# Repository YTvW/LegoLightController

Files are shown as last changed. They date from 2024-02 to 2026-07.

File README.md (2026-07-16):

# QBee LED Controller

A LEGO-stud-compatible LED controller board (Rev 1.0) built around the ATSAMD11C14A,
powered over USB-C. It drives up to two WS2812B (NeoPixel) strips and three
single-color LED channels.

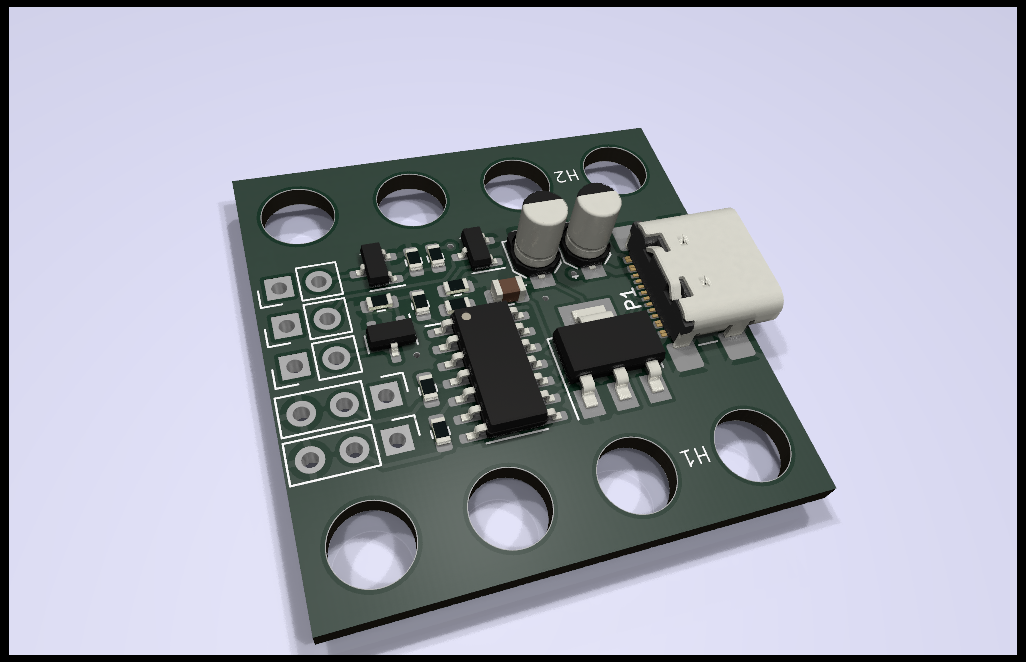
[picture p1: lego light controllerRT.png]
Board render


## Hardware overview

| Part | Function |
|---|---|
| U1 — ATSAMD11C14A (SOIC-14) | MCU, 16KB flash / 4KB RAM, native USB |
| U2 — AP2111H-3.3 | 3.3V LDO for the MCU |
| P1 — USB-C (USB4110) | Power (5V) + USB 2.0 data; 5.1k CC pulldowns identify the board as a power sink |
| Q1–Q3 — BC847 | Low-side switches for the three LED channels (1k base, 10k pulldown) |
| R10, R11 — 470Ω | Series resistors on the WS2812B data lines |

### Connectors / IO

| Connector | Pads | Signal | MCU pin | Arduino pin |
|---|---|---|---|---|
| J1 | 1: +5V, 2: switched GND | LED1 channel | PA02 | 2 |
| J2 | 1: +5V, 2: switched GND | LED2 channel | PA04 | 4 |
| J3 | 1: +5V, 2: switched GND | LED3 channel | PA05 | 5 |
| J4 | 1: +5V, 2: data, 3: GND | WS2812B strip (DL1) | PA14 | 14 |
| J5 | 1: +5V, 2: data, 3: GND | WS2812B strip (DL2) | PA15 | 15 |
| J7 | 1: 3V3, 2: RESET, 3: SWCLK, 4: SWDIO, 5: NC, 6: GND | SWD programming header (DNP) | PA28/PA30/PA31 | — |
| TP1 | test point | EXT1 spare GPIO | PA08 | 8 |
| TP2 | test point | EXT2 spare GPIO | PA09 | 9 |

The LED channels (J1–J3) switch the LED's ground side through a transistor:
connect an LED (with its own series resistor if needed) between pad 1 (+5V)
and pad 2. A HIGH on the MCU pin turns the channel on.

Notes per pin:

- **PA02 (LED1, pin 2)** has no timer output — hardware PWM is not possible.
  `analogWrite()` on this pin uses the true 10-bit DAC; the transistor makes
  this behave as a crude analog dimmer only. Prefer channels LED2/LED3 for
  smooth PWM dimming.
- **PA04/PA05 (LED2/LED3)** have TC1 waveform outputs (WO0/WO1) — used by
  `pwm_driver` channels 0 and 1.
- **PA14/PA15 (strips)** also carry TC1 outputs; do not `analogWrite()` them.

## Arduino environment setup

1. Install the [Arduino IDE](https://www.arduino.cc/en/software) (2.x).
2. Add the Fab SAM core: **File → Preferences → Additional boards manager URLs**:

   ```
   https://raw.githubusercontent.com/qbolsee/ArduinoCore-fab-sam/master/json/package_Fab_SAM_index.json
   ```

3. **Tools → Board → Boards Manager**, search "Fab SAM", install
   **Fab SAM core for Arduino** (this project was built with 1.12.0).
4. Select **Tools → Board → Fab SAM boards → Generic D11C14A**.

### Board settings (Tools menu)

| Setting | Value | Notes |
|---|---|---|
| Clock Source | `INTERNAL_USB_CALIBRATED_OSCILLATOR` | Crystalless; calibrates 48MHz from USB. Switch to `INTERNAL_OSCILLATOR` if USB is disabled. |
| Bootloader Size | `4KB_BOOTLOADER` | Leaves 12KB for the application |
| Serial Config | `NO_UART_ONE_WIRE_ONE_SPI` | Saves ~1.5KB vs the default; USB `Serial` still works. The hardware UART (`Serial1`) is not wired to anything on this board. |
| USB Config | `CDC_ONLY` | Needed for `Serial` debugging and one-click uploads |
| Float | default | |
| Timer PWM Frequency | default (732.4Hz) | Only affects `analogWrite()` |

### Uploading

Normal uploads go over USB via the SAM-BA bootloader: just press Upload —
the IDE opens the port at 1200 baud to reset the board into the bootloader
automatically (this requires the running sketch to have USB CDC enabled).

If the chip is blank, or the sketch was built without CDC, flash via the SWD
pads (J7) with a CMSIS-DAP programmer and
[edbg](https://github.com/ataradov/edbg), or use the IDE's
*Burn Bootloader* with the Fab programmer selected. Once the bootloader is
on, USB uploads work as above.

## Firmware (`QBee Software/QBeeFirmware`)

| File | Purpose |
|---|---|
| `QBeeFirmware.ino` | Main sketch |
| `ws2812b_dma_driver.c/h` | WS2812B driver using **TCC0** PWM + DMA. Non-blocking: `ws2812b_show()` starts a hardware transfer and returns immediately. Uses TCC0's double-buffered `CCB` compare register so bit timing is glitch-free and immune to interrupts/USB load. |
| `pwm_driver.c/h` | LED-channel PWM using **TC1** (channels 0/1 → pins 4/5). TC2 exists but its outputs land on the SWD pins only. Costs no flash while unused (linker GC). |
| `neopixel_driver.c/h` | Older bit-banged WS2812B driver (blocks with interrupts off; superseded by the DMA driver) |

### Timer budget

| Peripheral | Owner |
|---|---|
| TCC0 | `ws2812b_dma_driver` (do not combine with `analogWrite`/`pwm_driver` on TCC0 pins) |
| TC1 | `pwm_driver` channels 0/1 (pins 4/5). Also claimed by `tone()` — don't use both. |
| TC2 | `pwm_driver` channels 2/3 — outputs only on SWD pins PA30/PA31, effectively unusable |
| SysTick | `millis()`/`micros()`/`delay()` (not a shared peripheral) |
| DMAC ch 0 | `ws2812b_dma_driver` |

### Flash budget

The app space is 12288 bytes. Measured levers if space runs out:

| Change | Approx. saving |
|---|---|
| Serial Config → `NO_UART...` | 1.5KB (free — `Serial1` unused) |
| USB Config → `WITHOUT_CDC` (drop `Serial` prints) | +2KB |
| USB Config → `USB_DISABLED` (also set Clock → `INTERNAL_OSCILLATOR`) | +4KB more |
| Bootloader → `NO_BOOTLOADER` (SWD uploads only) | +4KB of app space |

## Known hardware issues (Rev 1.0)

- **No level shifter on the WS2812B data lines.** Data is 3.3V while the
  strip runs at 5V; the strip's VIH spec is 0.7×VDD = 3.5V, so operation
  relies on real-world margin. Symptom: strips work on a USB-C wall supply
  but fail or glitch on some PC ports (slightly higher/noisier VBUS).
  Workaround: a silicon diode in series with the strip's +5V feed (drops
  strip VDD to ~4.4V). Proper fix for Rev 2: a 74AHCT1G125 / SN74LV1T125
  buffer on each data line, powered from 5V.
- **LED1 (PA02) has no hardware PWM** — see pin notes above.

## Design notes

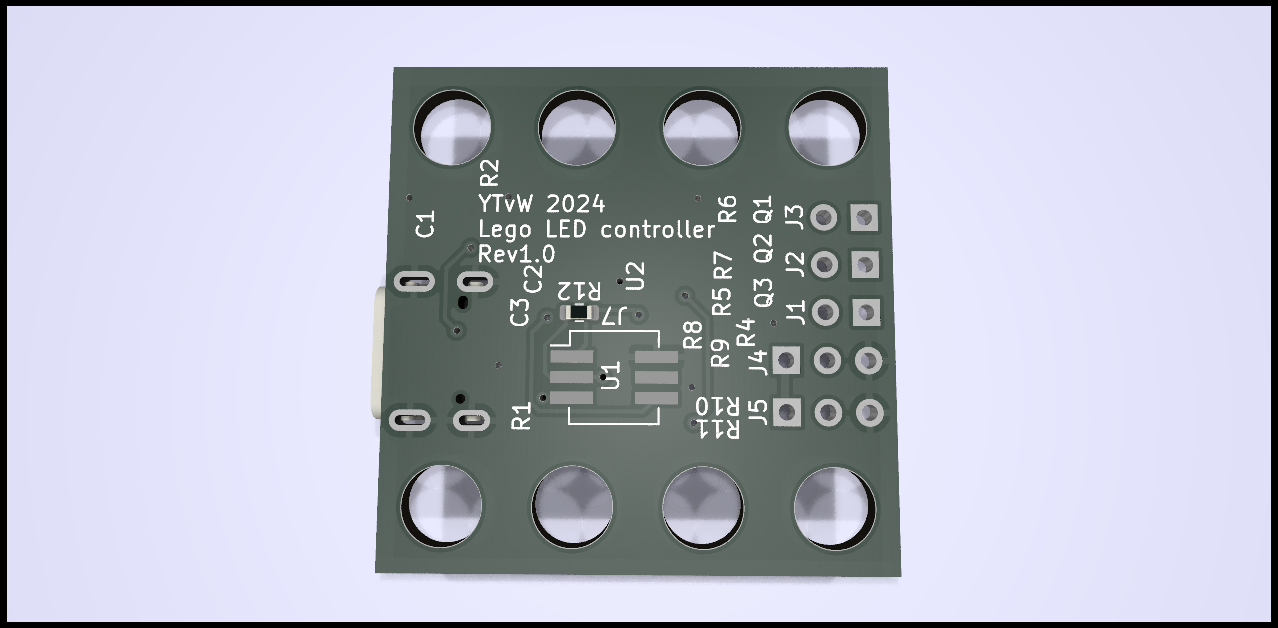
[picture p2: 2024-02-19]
lego light controllerRT2.png

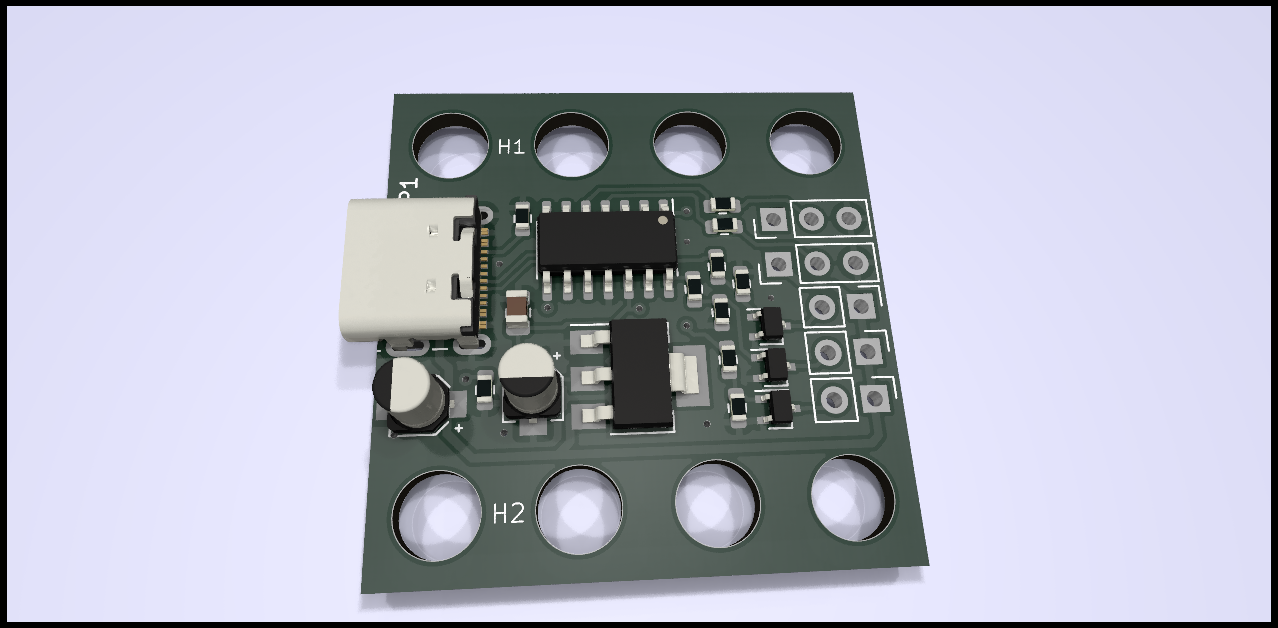
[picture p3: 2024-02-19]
lego light controllerRT1.png

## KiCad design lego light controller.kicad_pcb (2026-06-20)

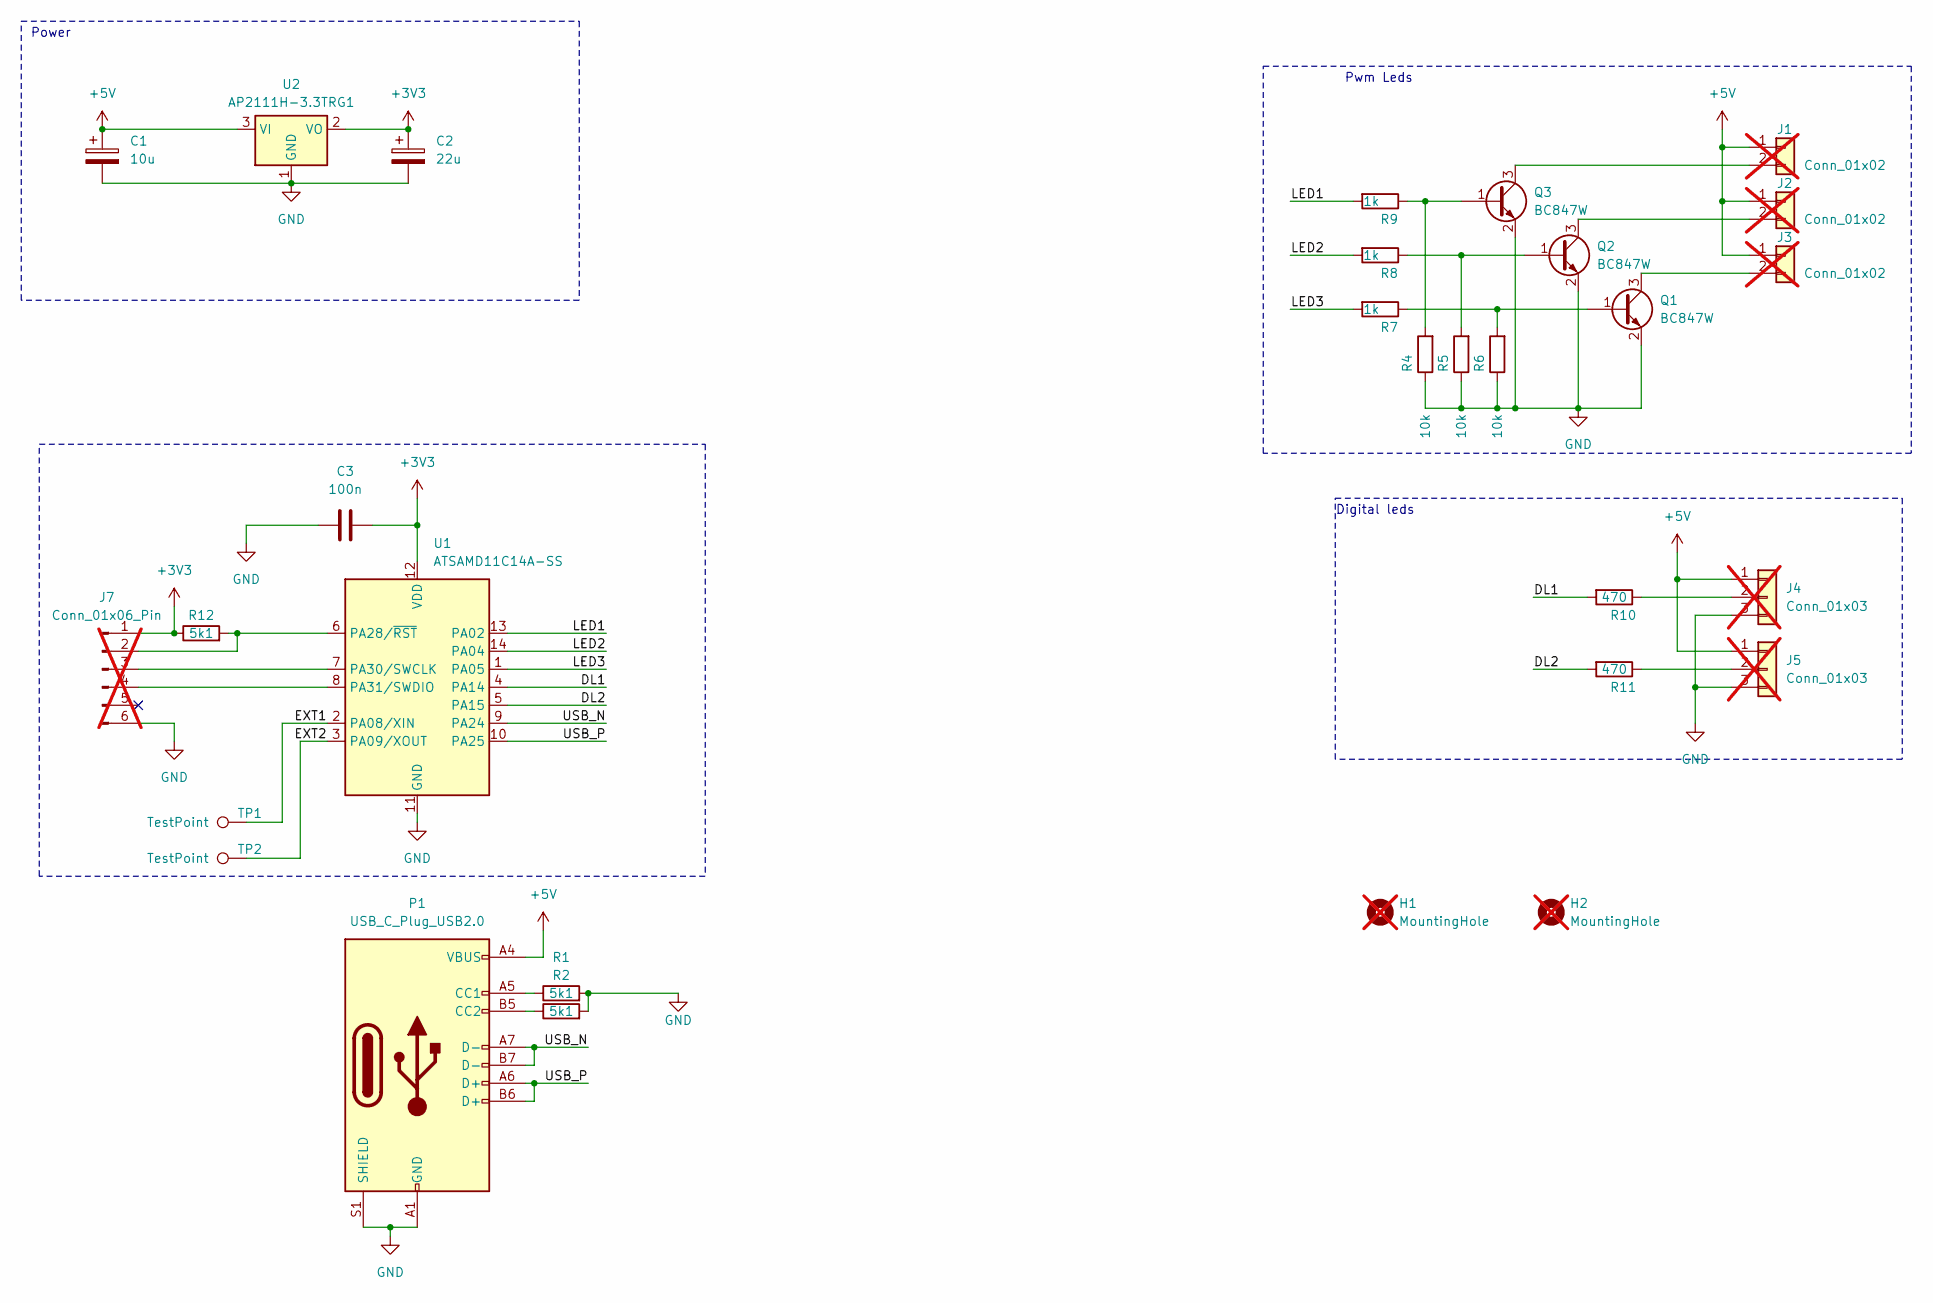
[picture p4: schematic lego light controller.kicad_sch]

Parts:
C1: 10u; CP_Elec_3x5.3; MPN 875105240001
C2: 22u; CP_Elec_3x5.3; MPN 875105240003
C3: 100n; C_0805_2012Metric
H1, H2: MountingHole; LEGO 4Studs; not fitted
J1, J2, J3: Conn_01x02; PinHeader_1x02_P2.54mm_Vertical; not fitted
J4, J5: Conn_01x03; PinHeader_1x03_P2.54mm_Vertical; not fitted
J7: Conn_01x06_Pin; SW_DIP_SPSTx03_Slide_KingTek_DSHP03TJ_W5.25mm_P1.27mm_JPin; not fitted
P1: USB_C_Plug_USB2.0; USB_C_Receptacle_GCT_USB4110; MPN USB4110-GF-A
Q1, Q2, Q3: BC847W; SOT-23; MPN BC817-16LT3G
R1, R2, R12: 5k1; R_0603_1608Metric
R4, R5, R6: 10k; R_0603_1608Metric
R7, R8, R9: 1k; R_0603_1608Metric
R10, R11: 470; R_0603_1608Metric
TP1, TP2: TestPoint; TestPoint_Pad_2.0x2.0mm
U1: ATSAMD11C14A-SS; SOIC-14_3.9x8.7mm_P1.27mm; MPN ATSAMD11C14A-SSNT
U2: AP2111H-3.3TRG1; SOT-223-3_TabPin2; MPN AP2111H-3.3TRG1

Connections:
+3V3: C2.1, C3.2, J7.1, R12.1, U1.12 (VDD), U2.2 (VO)
+5V: C1.1, J1.1, J2.1, J3.1, J4.1, J5.1, P1.A4 (VBUS), P1.A9 (VBUS), P1.B4 (VBUS), P1.B9 (VBUS), U2.3 (VI)
/DL1: R10.2, U1.4 (PA14)
/DL2: R11.2, U1.5 (PA15)
/EXT1: TP1.1 (1_1), U1.2 (PA08/XIN)
/EXT2: TP2.1 (1_1), U1.3 (PA09/XOUT)
/LED1: R9.2, U1.13 (PA02)
/LED2: R8.2, U1.14 (PA04)
/LED3: R7.2, U1.1 (PA05)
/USB_N: P1.A7 (D-), P1.B7 (D-), U1.9 (PA24)
/USB_P: P1.A6 (D+), P1.B6 (D+), U1.10 (PA25)
GND: C1.2, C2.2, C3.1, J4.3, J5.3, J7.6, P1.A1 (GND), P1.A12 (GND), P1.B1 (GND), P1.B12 (GND), P1.S1 (SHIELD), Q1.2 (E), Q2.2 (E), Q3.2 (E), R1.2, R2.2, R4.1, R5.1, R6.1, U1.11 (GND), U2.1 (GND)
unnamed: J1.2, Q3.3 (C)
unnamed: J2.2, Q2.3 (C)
unnamed: J3.2, Q1.3 (C)
unnamed: J4.2, R10.1
unnamed: J5.2, R11.1
unnamed: J7.2, R12.2, U1.6 (PA28/~RST)
unnamed: J7.3, U1.7 (PA30/SWCLK)
unnamed: J7.4, U1.8 (PA31/SWDIO)
unnamed: P1.A5 (CC1), R1.1
unnamed: P1.B5 (CC2), R2.1
unnamed: Q1.1 (B), R6.2, R7.1
unnamed: Q2.1 (B), R5.2, R8.1
unnamed: Q3.1 (B), R4.2, R9.1

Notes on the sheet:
Power
Pwm Leds
Digital leds

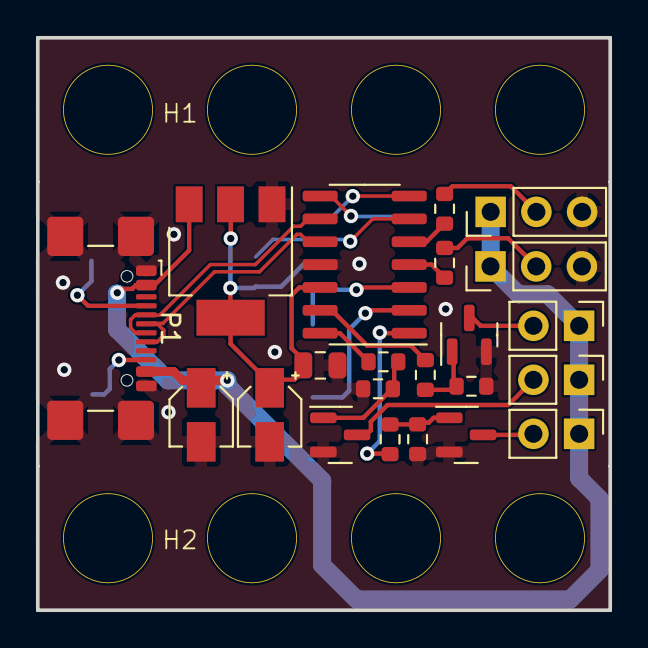
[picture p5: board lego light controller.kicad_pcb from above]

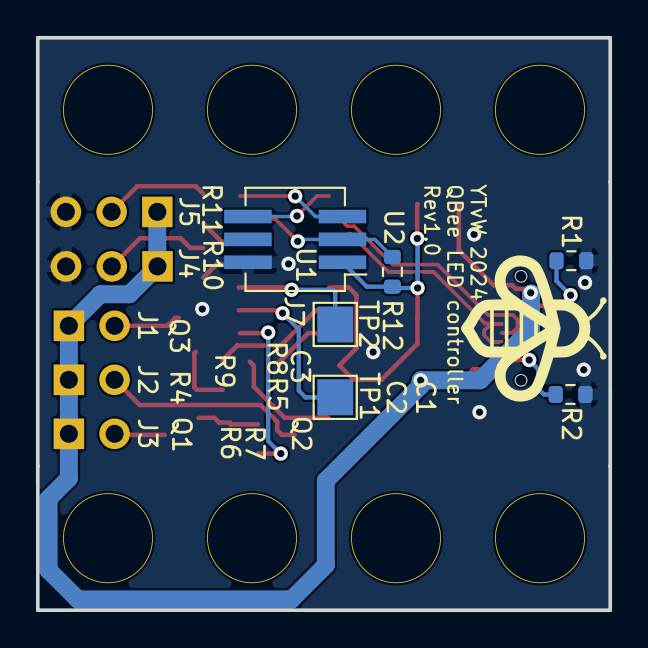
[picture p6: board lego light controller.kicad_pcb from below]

Board: 2 copper layers, 31.8 x 31.8 mm, 30 parts (6 on the bottom side), 25 nets.

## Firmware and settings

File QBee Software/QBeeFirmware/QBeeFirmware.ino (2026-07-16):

// #include <Adafruit_NeoPixel.h>
// #include "pwm_driver.h"
// #include "neopixel_driver.h"
#include "ws2812b_dma_driver.h"

ws2812b_strip_t strip;
ws2812b_strip_t strip2;

#define PIXEL_PIN_1 15
#define PIXEL_PIN_2 14

#define PWM_PIN_2 4
#define PWM_PIN_3 5

// constants won't change. Used here to set a pin number:
const int ledPin1 = 2;
const int ledPin2 = PWM_PIN_2;
const int ledPin3 = PWM_PIN_3;

int ledState = 0;  // ledState used to set the LED

unsigned long previousMillis = 0;  // will store last time LED was updated

const long interval = 500;  // interval at which to blink (milliseconds)

// neopixel_strip_t strip;
// neopixel_strip_t strip2;

// Adafruit_NeoPixel strip1 = Adafruit_NeoPixel(8, PIXEL_PIN_1, NEO_GRB + NEO_KHZ800);

void setup() {
  Serial.begin(115200);
  // while (!Serial) {
  //   ;  // wait for serial port to connect. Needed for native USB port only
  // }    // prints title with ending line break
  Serial.println("running set up");
  pinMode(ledPin1, OUTPUT);
  pinMode(ledPin2, OUTPUT);
  pinMode(ledPin3, OUTPUT);

  ws2812b_init(&strip, PIXEL_PIN_1, 8, WS2812B_GRB, NULL);
  ws2812b_init(&strip2, PIXEL_PIN_2, 8, WS2812B_GRB, NULL);
  ws2812b_set_brightness(&strip, 64);

  ws2812b_fill(&strip, 0, 0, 0);
  ws2812b_fill(&strip2, 0, 0, 0);
  ws2812b_show(&strip);
  ws2812b_show(&strip2);
}
uint8_t ledNr = 0;
uint32_t colour =ws2812b_color(255, 255,255);
void loop() {

  // check to see if it's time to blink the LED; that is, if the difference
  // between the current time and last time you blinked the LED is bigger than
  // the interval at which you want to blink the LED.
  unsigned long currentMillis = millis();

  if (currentMillis - previousMillis >= interval) {
    // save the last time you blinked the LED

    previousMillis = currentMillis;
    Serial.print("ledNr: ");
    Serial.println(ledNr);
    // if the LED is off turn it on and vice-versa:
    ws2812b_set_pixel_color(&strip, ledNr, colour);
    if (ledState == 64) {
      ledState = 200;

    } else {
      


      ledState = 64;
    }

    // CPU is free while LEDs update
    if (ws2812b_is_ready(&strip)) {
      // Start next update
      Serial.println("updating leds: ");

      ws2812b_show(&strip);
    } else {
      Serial.println("leds not ready");
    }
    ledNr += 1;
    if (ledNr >= 8) {
      ledNr = 0;
      Serial.print("colour");
      Serial.println(colour);
      if (colour == 0) {
      colour = ws2812b_color(255, 0,0);
      }else {
      colour = ws2812b_color(0, 0,0);
      
      }
    }
    // neopixel_show(&strip);
    // strip1.show();
    // pwm_set_duty(PWM_CHANNEL_2, ledState);  // 50%
    // pwm_set_duty(PWM_CHANNEL_3, 64);   // 25%
    //   // set the LED with the ledState of the variable:
    // analogWrite(ledPin2, ledState);
    // analogWrite(ledPin3, 255 - ledState);
  }

  //  rainbowCycle(strip2,20);
}

// Slightly different, this makes the rainbow equally distributed throughout
// void rainbowCycle(Adafruit_NeoPixel strip, uint8_t wait) {
//   uint16_t i, j;

//   for (j = 0; j < 256 * 5; j++) {  // 5 cycles of all colors on wheel
//     for (i = 0; i < strip.numPixels(); i++) {
//       strip.setPixelColor(i, Wheel(strip, ((i * 256 / strip.numPixels()) + j) & 255));
//     }
//     strip.show();
//     delay(wait);
//   }
// }

// Input a value 0 to 255 to get a color value.
// The colours are a transition r - g - b - back to r.
// uint32_t Wheel(Adafruit_NeoPixel strip, byte WheelPos) {
//   WheelPos = 255 - WheelPos;
//   if (WheelPos < 85) {
//     return strip.Color(255 - WheelPos * 3, 0, WheelPos * 3);
//   }
//   if (WheelPos < 170) {
//     WheelPos -= 85;
//     return strip.Color(0, WheelPos * 3, 255 - WheelPos * 3);
//   }
//   WheelPos -= 170;
//   return strip.Color(WheelPos * 3, 255 - WheelPos * 3, 0);
// }

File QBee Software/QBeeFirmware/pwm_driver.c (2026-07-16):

/**
 * @file pwm_driver.c
 * @brief TC-based PWM driver implementation for SAMD11C / SAMD21
 *
 * Uses two TC instances in 8-bit PWM mode, leaving TCC0 free for the
 * WS2812B DMA driver:
 *   - SAMD11C: TC1 (channels 0-1) and TC2 (channels 2-3)
 *   - SAMD21:  TC3 (channels 0-1) and TC4 (channels 2-3)
 */

#include "pwm_driver.h"

// The two TC instances backing the four PWM channels, and their GCLK
// channel IDs. On the SAMD11 TC1/TC2 share one GCLK channel; on the
// SAMD21 TC3 (paired with TCC2) and TC4 (paired with TC5) each sit on
// their own.
#if defined(_SAMD21_)
#define PWM_TC_A TC3
#define PWM_TC_B TC4
#define PWM_TC_A_GCLK_ID TC3_GCLK_ID
#define PWM_TC_B_GCLK_ID TC4_GCLK_ID
#define PWM_APBCMASK (PM_APBCMASK_TC3 | PM_APBCMASK_TC4)
#else // _SAMD11_
#define PWM_TC_A TC1
#define PWM_TC_B TC2
#define PWM_TC_A_GCLK_ID TC1_GCLK_ID
#define PWM_TC_B_GCLK_ID TC1_GCLK_ID // TC1 and TC2 share one GCLK channel
#define PWM_APBCMASK (PM_APBCMASK_TC1 | PM_APBCMASK_TC2)
#endif

// Pin mapping table - maps port pins to TC waveform outputs.
// Pins are matched through g_APinDescription, so Arduino pin numbers
// resolve correctly on any board variant.
static const struct
{
  uint8_t port;    // 0 = PORTA, 1 = PORTB
  uint8_t portPin; // pin number within the port
  uint8_t channel; // PWM channel (0-1 = TC A CC0/CC1, 2-3 = TC B CC0/CC1)
  uint8_t mux;     // PMUX function
} pinMap[] = {
#if defined(_SAMD21_)
    // SAMD21 TC Pin Mapping (PMUX Function E = 0x04)
    {0, 14, 0, PORT_PMUX_PMUXE_E_Val}, // PA14 -> TC3/WO[0]
    {0, 15, 1, PORT_PMUX_PMUXE_E_Val}, // PA15 -> TC3/WO[1]
    {0, 18, 0, PORT_PMUX_PMUXE_E_Val}, // PA18 -> TC3/WO[0] (alt)
    {0, 19, 1, PORT_PMUX_PMUXE_E_Val}, // PA19 -> TC3/WO[1] (alt)
    {0, 22, 2, PORT_PMUX_PMUXE_E_Val}, // PA22 -> TC4/WO[0]
    {0, 23, 3, PORT_PMUX_PMUXE_E_Val}, // PA23 -> TC4/WO[1]
    {1, 8, 2, PORT_PMUX_PMUXE_E_Val},  // PB08 -> TC4/WO[0] (alt, G/J parts)
    {1, 9, 3, PORT_PMUX_PMUXE_E_Val},  // PB09 -> TC4/WO[1] (alt, G/J parts)
#else
    // SAMD11C14A TC Pin Mapping (PMUX Function E = 0x04)
    // Note: PA08/PA09 have no TC waveform outputs on the SAMD11, only TCC0.
    {0, 4, 0, PORT_PMUX_PMUXE_E_Val},  // PA04 -> TC1/WO[0]
    {0, 5, 1, PORT_PMUX_PMUXE_E_Val},  // PA05 -> TC1/WO[1]
    {0, 14, 0, PORT_PMUX_PMUXE_E_Val}, // PA14 -> TC1/WO[0] (alt - normally WS2812B strip 2)
    {0, 15, 1, PORT_PMUX_PMUXE_E_Val}, // PA15 -> TC1/WO[1] (alt - normally WS2812B strip 1)
    {0, 30, 2, PORT_PMUX_PMUXE_E_Val}, // PA30 -> TC2/WO[0] (WARNING: SWCLK programming pin)
    {0, 31, 3, PORT_PMUX_PMUXE_E_Val}, // PA31 -> TC2/WO[1] (WARNING: SWDIO programming pin)
#endif
};
#define PIN_MAP_SIZE (sizeof(pinMap) / sizeof(pinMap[0]))

// Internal state
static bool pwmInitialized = false;
static uint16_t channelDuty[PWM_NUM_CHANNELS] = {0};
static uint8_t channelEnabled = 0; // Bitmask of enabled channels
static uint32_t currentPeriod = 0;
static uint8_t currentPrescaler = TC_CTRLA_PRESCALER_DIV1_Val;

/**
 * @brief Get the TC instance serving a channel (0-1 = TC A, 2-3 = TC B)
 */
static inline Tc *tcForChannel(uint8_t channel)
{
  return (channel < 2) ? PWM_TC_A : PWM_TC_B;
}

/**
 * @brief Get the CC register index for a channel within its TC
 */
static inline uint8_t ccIndexForChannel(uint8_t channel)
{
  return channel & 1;
}

/**
 * @brief Find pin configuration in the mapping table
 *
 * Resolves the Arduino pin to its port/pin through g_APinDescription
 * (GetPort/GetPin work with every variant pin-table layout), then matches
 * against the port pin map.
 */
static int findPinConfig(uint8_t pin)
{
  uint8_t portPin = GetPin(pin);
  uint8_t portNum = GetPort(pin);

  for (size_t i = 0; i < PIN_MAP_SIZE; i++)
  {
    if (pinMap[i].port == portNum && pinMap[i].portPin == portPin)
    {
      return (int)i;
    }
  }
  return -1;
}

/**
 * @brief Configure port pin for TC output
 */
static void configurePinMux(uint8_t port, uint8_t portPin, uint8_t mux)
{
  // Enable pin multiplexing
  if (portPin & 1)
  {
    // Odd pin - use PMUXO
    PORT->Group[port].PMUX[portPin >> 1].bit.PMUXO = mux;
  }
  else
  {
    // Even pin - use PMUXE
    PORT->Group[port].PMUX[portPin >> 1].bit.PMUXE = mux;
  }
  // Enable peripheral multiplexer for this pin
  PORT->Group[port].PINCFG[portPin].bit.PMUXEN = 1;
}

/**
 * @brief Sync wait helper for TC
 */
static inline void syncTC(Tc *tc)
{
  while (tc->COUNT8.STATUS.bit.SYNCBUSY)
  {
    // Wait for synchronization
  }
}

/**
 * @brief Calculate prescaler and 8-bit period for a target frequency
 *
 * TC in 8-bit mode has an 8-bit PER register, so the period is capped
 * at 255 (unlike TCC0's 24-bit counter). freq = 48MHz / (prescaler * (PER+1)).
 * Reachable range is ~184Hz (DIV1024, PER=255) to ~188kHz (DIV1, PER=255);
 * out-of-range requests are clamped.
 */
static void calcTimebase(uint32_t frequencyHz, uint8_t *prescalerOut, uint32_t *periodOut)
{
  uint32_t clockFreq = 48000000UL; // Assuming 48MHz GCLK0
  uint32_t prescalerValues[] = {1, 2, 4, 8, 16, 64, 256, 1024};
  uint8_t prescalerBits[] = {
      TC_CTRLA_PRESCALER_DIV1_Val,
      TC_CTRLA_PRESCALER_DIV2_Val,
      TC_CTRLA_PRESCALER_DIV4_Val,
      TC_CTRLA_PRESCALER_DIV8_Val,
      TC_CTRLA_PRESCALER_DIV16_Val,
      TC_CTRLA_PRESCALER_DIV64_Val,
      TC_CTRLA_PRESCALER_DIV256_Val,
      TC_CTRLA_PRESCALER_DIV1024_Val};

  // Fallback: slowest possible timebase
  uint8_t prescaler = TC_CTRLA_PRESCALER_DIV1024_Val;
  uint32_t period = PWM_MAX_VALUE;

  if (frequencyHz == 0)
  {
    frequencyHz = 1;
  }

  // Pick the smallest prescaler whose period fits in 8 bits,
  // maximizing duty cycle resolution
  for (int i = 0; i < 8; i++)
  {
    uint32_t testPeriod = clockFreq / prescalerValues[i] / frequencyHz;
    if (testPeriod < 2)
    {
      testPeriod = 2; // Frequency too high - clamp
    }
    if ((testPeriod - 1) <= PWM_MAX_VALUE)
    {
      prescaler = prescalerBits[i];
      period = testPeriod - 1;
      break;
    }
  }

  *prescalerOut = prescaler;
  *periodOut = period;
}

/**
 * @brief Apply mode, prescaler and period to one TC (must be called with TC disabled)
 */
static void configureTC(Tc *tc, uint8_t prescaler, uint32_t period)
{
  // Reset the TC
  tc->COUNT8.CTRLA.reg = TC_CTRLA_SWRST;
  syncTC(tc);
  while (tc->COUNT8.CTRLA.bit.SWRST)
    ;

  // 8-bit counter mode, single-slope PWM, prescaler
  // (CTRLA is enable-protected, so everything goes in one write)
  tc->COUNT8.CTRLA.reg = TC_CTRLA_MODE_COUNT8 |
                         TC_CTRLA_WAVEGEN_NPWM |
                         TC_CTRLA_PRESCALER(prescaler) |
                         TC_CTRLA_PRESCSYNC_GCLK;
  syncTC(tc);

  // Set period (TOP value)
  tc->COUNT8.PER.reg = (uint8_t)period;
  syncTC(tc);

  // Initialize both compare channels to 0 (0% duty)
  tc->COUNT8.CC[0].reg = 0;
  syncTC(tc);
  tc->COUNT8.CC[1].reg = 0;
  syncTC(tc);

  // Enable
  tc->COUNT8.CTRLA.reg |= TC_CTRLA_ENABLE;
  syncTC(tc);
}
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

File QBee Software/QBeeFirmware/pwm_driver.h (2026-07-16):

/**
 * @file pwm_driver.h
 * @brief TC-based PWM driver for SAMD11C / SAMD21
 *
 * Uses two TC hardware peripherals for efficient PWM generation,
 * leaving TCC0 free for the WS2812B DMA driver. The chip is selected
 * automatically at compile time.
 *
 * Channel to pin mapping on the SAMD11C14A (TC1/TC2):
 *   - Channel 0: PA04 (TC1/WO[0]) or PA14
 *   - Channel 1: PA05 (TC1/WO[1]) or PA15
 *   - Channel 2: PA30 (TC2/WO[0]) - SWCLK programming pin!
 *   - Channel 3: PA31 (TC2/WO[1]) - SWDIO programming pin!
 *
 * PA14/PA15 are normally taken by the WS2812B strips, and channels 2/3
 * sacrifice the SWD debug port, so PA04 and PA05 are the practical choices.
 *
 * Channel to pin mapping on the SAMD21 (TC3/TC4):
 *   - Channel 0: PA14 (TC3/WO[0]) or PA18
 *   - Channel 1: PA15 (TC3/WO[1]) or PA19
 *   - Channel 2: PA22 (TC4/WO[0]) or PB08 (G/J parts)
 *   - Channel 3: PA23 (TC4/WO[1]) or PB09 (G/J parts)
 *
 * Note: pwm_deinit() on the SAMD21 also gates the GCLK channels shared
 * with TCC2 and TC5 (which analogWrite may be using on their pins).
 *
 * TC counters run in 8-bit mode, so the PWM frequency range is
 * ~184Hz to ~188kHz (out-of-range requests are clamped).
 */

#ifndef PWM_DRIVER_H
#define PWM_DRIVER_H

#include <Arduino.h>
#include <sam.h>

#ifdef __cplusplus
extern "C" {
#endif

// PWM configuration
#define PWM_RESOLUTION_BITS   8
#define PWM_MAX_VALUE         ((1 << PWM_RESOLUTION_BITS) - 1)  // 255 for 8-bit
#define PWM_DEFAULT_FREQ_HZ   1000

// Channel indices
#define PWM_CHANNEL_0   0
#define PWM_CHANNEL_1   1
#define PWM_CHANNEL_2   2
#define PWM_CHANNEL_3   3
#define PWM_NUM_CHANNELS 4

/**
 * @brief PWM channel configuration structure
 */
typedef struct {
    uint8_t pin;           // Arduino pin number
    uint8_t portPin;       // Port pin (PA number)
    uint8_t wo;            // Waveform output number (0-3 or 4-7 for inverted)
    uint8_t muxFunction;   // PMUX function (E or F typically for TCC)
} pwm_channel_config_t;

/**
 * @brief Initialize the TC1/TC2 PWM driver
 *
 * @param frequencyHz PWM frequency in Hz (e.g., 1000 for 1kHz)
 * @return true if initialization successful, false otherwise
 */
bool pwm_init(uint32_t frequencyHz);

/**
 * @brief Configure a specific pin for PWM output
 * 
 * @param channel Channel index (0-3)
 * @param pin Arduino pin number
 * @return true if configuration successful, false if pin not supported
 */
bool pwm_configure_channel(uint8_t channel, uint8_t pin);

/**
 * @brief Set the duty cycle for a PWM channel
 * 
 * @param channel Channel index (0-3)
 * @param duty Duty cycle (0 to PWM_MAX_VALUE, i.e., 0-255 for 8-bit)
 */
void pwm_set_duty(uint8_t channel, uint16_t duty);

/**
 * @brief Set duty cycle as a percentage
 * 
 * @param channel Channel index (0-3)
 * @param percent Duty cycle percentage (0.0 to 100.0)
 */
void pwm_set_duty_percent(uint8_t channel, float percent);

/**
 * @brief Enable PWM output on a channel
 * 
 * @param channel Channel index (0-3)
 */
void pwm_enable_channel(uint8_t channel);

/**
 * @brief Disable PWM output on a channel (output goes low)
 * 
 * @param channel Channel index (0-3)
 */
void pwm_disable_channel(uint8_t channel);

/**
 * @brief Get current duty cycle value for a channel
 * 
 * @param channel Channel index (0-3)
 * @return Current duty cycle value
 */
uint16_t pwm_get_duty(uint8_t channel);

/**
 * @brief Set PWM frequency (affects all channels)
 * 
 * @param frequencyHz New frequency in Hz
 */
void pwm_set_frequency(uint32_t frequencyHz);

/**
 * @brief Deinitialize the PWM driver and release resources
 */
void pwm_deinit(void);

#ifdef __cplusplus
}
#endif

#endif // PWM_DRIVER_H

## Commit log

2024-02-17 add progress so far
    [lego light controller.kicad_pcb, lego light controller.kicad_sch]
2024-02-17 make schema neat
    [lego light controller.kicad_sch]
2024-02-18 add values and update usb c
    [lego light controller.kicad_pcb, lego light controller.kicad_sch]
2024-02-19 change logo size
    [lego light controller.kicad_pcb]
2024-02-19 clean up pcb
    [lego light controller.kicad_pcb]
2024-02-19 fix trace to moved component
    [lego light controller.kicad_pcb]
2024-02-19 fix track to 3v3 outpu
    [lego light controller.kicad_pcb]
2024-02-21 update footprints and redo layout
    [lego light controller.kicad_pcb, lego light controller.kicad_sch]
2024-02-22 move usb to center
    [lego light controller.kicad_pcb]
2024-02-22 add pads to unused io
    [lego light controller.kicad_pcb, lego light controller.kicad_sch]
2024-02-26 update to kicad v8
    [lego light controller.kicad_pcb, lego light controller.kicad_sch]
2024-02-26 fix pcb name
    [lego light controller.kicad_pcb]
2024-02-26 fix BOM
    [lego light controller.kicad_pcb, lego light controller.kicad_sch]
2026-06-20 small fixes
    [lego light controller.kicad_pcb]
2026-07-08 fix major bug with ws2812 driver bricking the board if 2 channels used
    [QBeeFirmware.ino, ws2812b_dma_driver.c]
2026-07-14 add samd21 mapping to drivers for the upcoming v2
